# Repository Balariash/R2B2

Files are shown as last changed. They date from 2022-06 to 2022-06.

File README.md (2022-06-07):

# R2B2
Double click on index.html to open the web interface.

# Mosquitto
The file mosquitto.conf is needed to use MQTT over websockets.

Place this file in /etc/mosquitto/conf.d/ directory.

# Python
You need to specificate the IP of MQTT Broker in the variable host from config.py to use mqtt_client.py script

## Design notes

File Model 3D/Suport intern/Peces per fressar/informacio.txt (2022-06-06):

Informació sobre les peces:

Suport de la càmera:

    - El gruix de la pesa ha de ser de uns 5mm.
    - Els quatre forats petits són de 2mm de diàmetre, la mateixa mida que els forats de la càmera.
    - Els dos forats més grans són de 6mm de diàmetre per permetre passar una barra roscada.
    - El costat curt del rectangle de mesurar entre 6 i 8mm.

Suport de la batèria LIPO:
    
    - El gruix ha de ser de uns 8mm.
    - Els dos forats menors han de ser de 4mm de diàmetre.
    - Els tres forats majors han de ser de 6mm de diàmetre.

Suport de la batèria de la Raspberry:

    - El gruix ha de ser de uns 8mm.
    - Els dos forats menors han de ser de 4mm de diàmetre.
    - El forat gran ha de ser de 6mm de diàmetre.
    - Els extrems poden quedar arrodonits.

Barra de unió:

    - El gruix de la barra ha de ser de 6~7mm-
    - Els forats han de ser de 4mm.
    - Són necessàries dues peces d'aquest tipus.

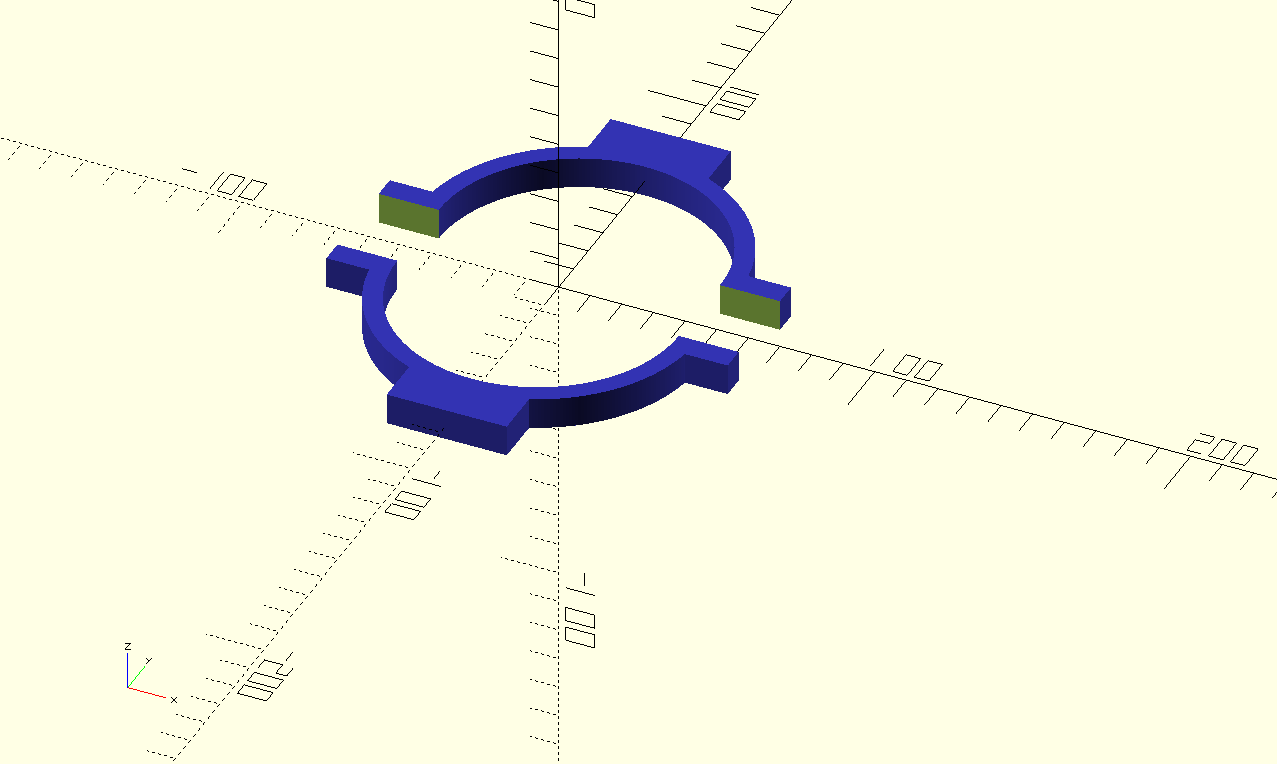
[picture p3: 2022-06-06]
Model 3D/Peces/imatges/anell_posterior_v2.png

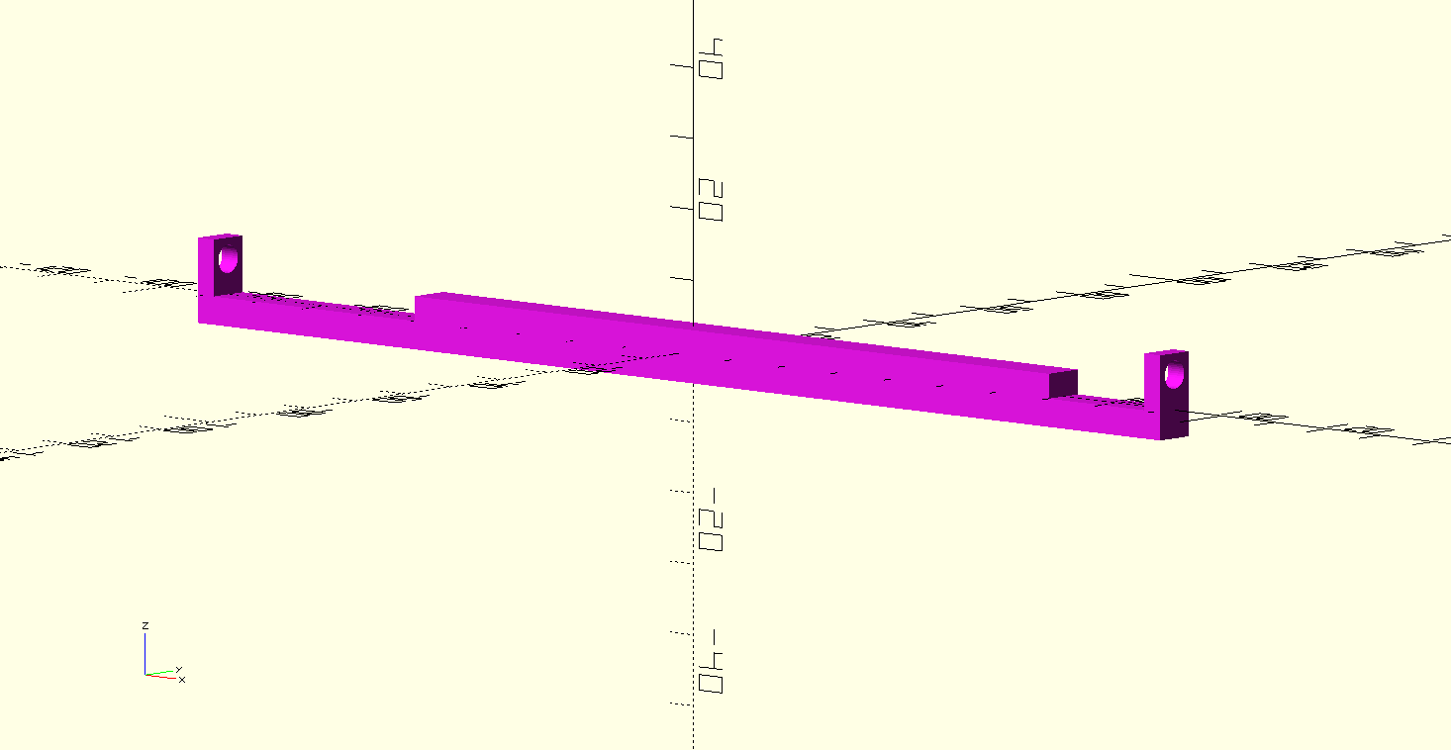
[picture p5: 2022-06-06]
Model 3D/Suport intern/Peces per fressar/Imatges/barra_unio_2.png

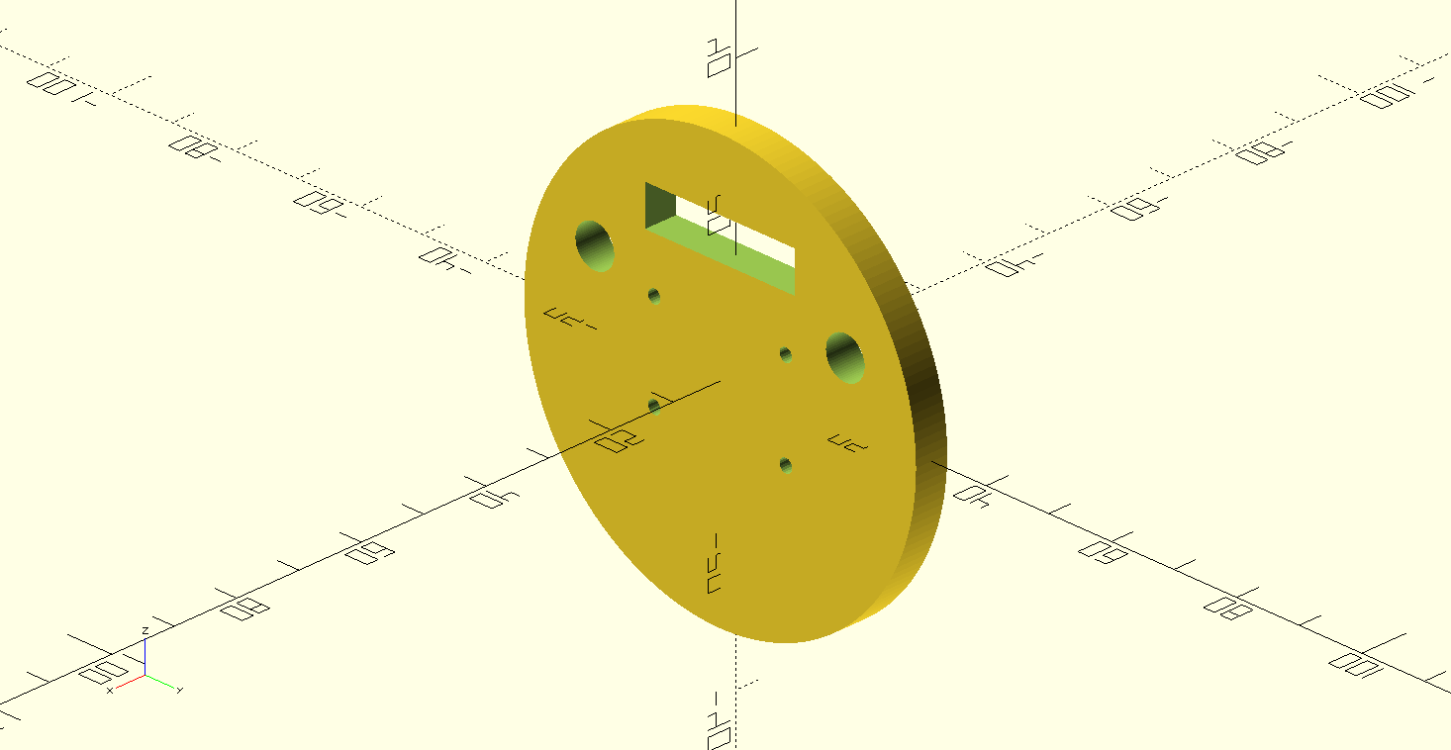
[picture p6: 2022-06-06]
Model 3D/Suport intern/Peces per fressar/Imatges/suport_camera_1.png

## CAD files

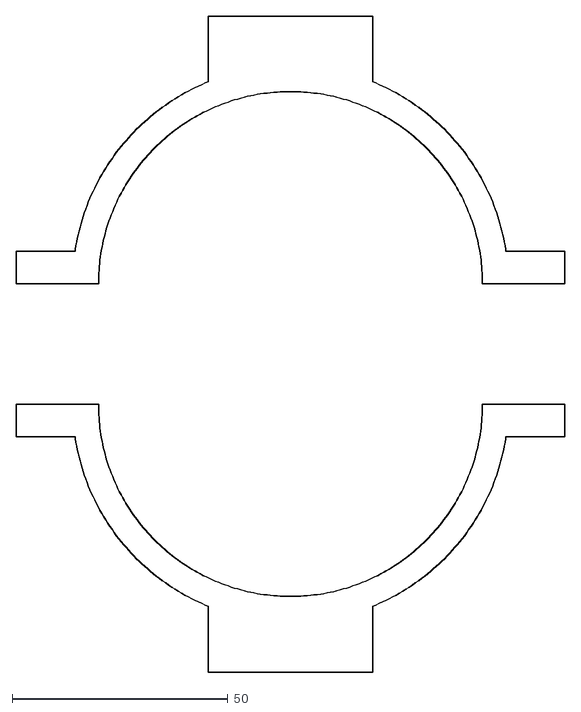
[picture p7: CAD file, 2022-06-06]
Model 3D/Peces/dxf/anell_posterior_v2.dxf
126.9 x 151.9

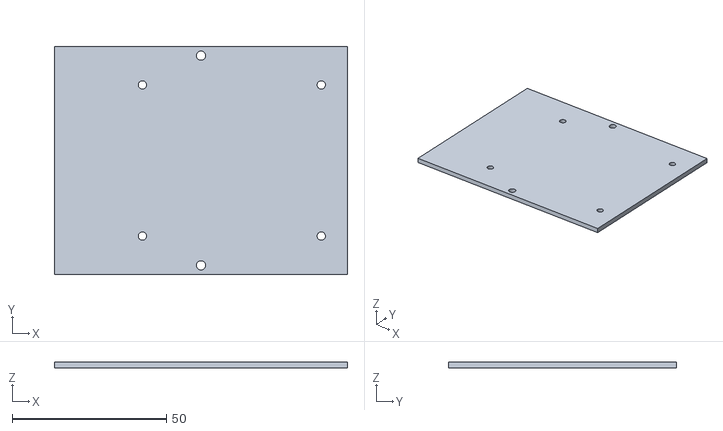
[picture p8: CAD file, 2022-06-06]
Model 3D/Suport intern/Impressió 3D/suport_raspi.stl
95.0 x 74.0 x 2.00

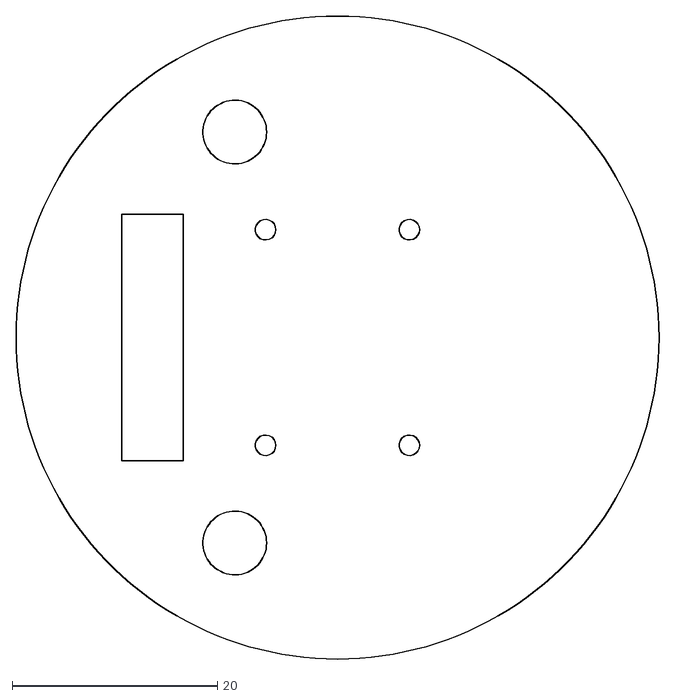
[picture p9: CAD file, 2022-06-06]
Model 3D/Suport intern/Peces per fressar/dxf/suport_camera.dxf
62.6 x 62.6

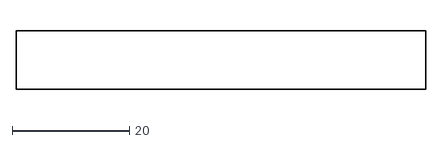
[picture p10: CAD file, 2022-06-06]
Model 3D/topes/dxf/barra.dxf
70.0 x 10.0

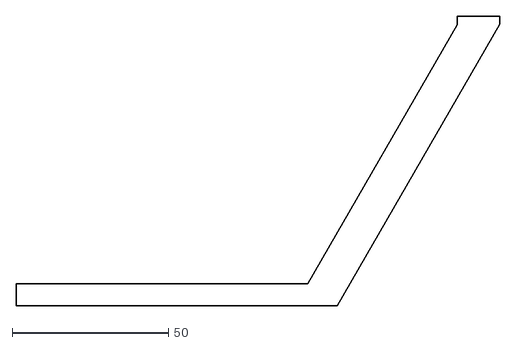
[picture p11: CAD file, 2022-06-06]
Model 3D/Peces/dxf/suport_motor_horitz.dxf
154.5 x 92.5

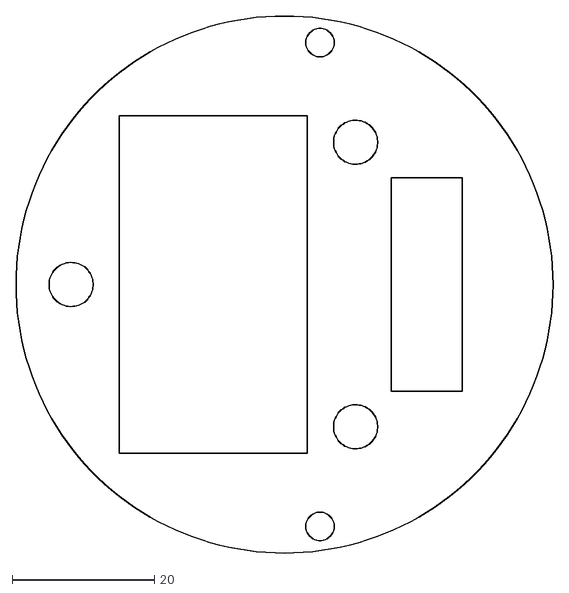
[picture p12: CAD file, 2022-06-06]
Model 3D/Suport intern/Peces per fressar/dxf/suport_lipo.dxf
75.5 x 75.5

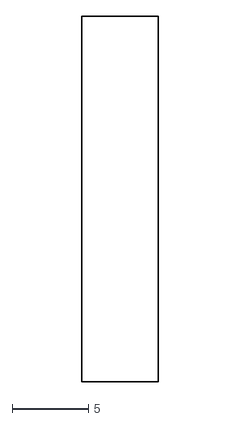
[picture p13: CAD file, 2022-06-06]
Model 3D/topes/dxf/tope_davanter.dxf
5.00 x 24.0

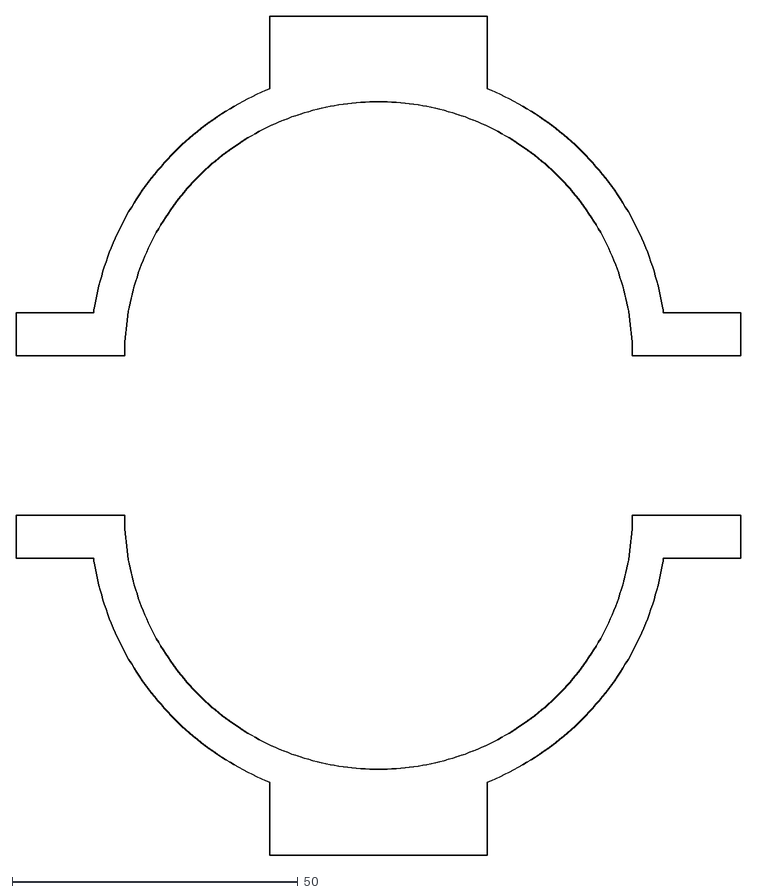
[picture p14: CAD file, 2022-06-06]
Model 3D/Peces/dxf/anell_davanter_v2.dxf
126.9 x 146.9

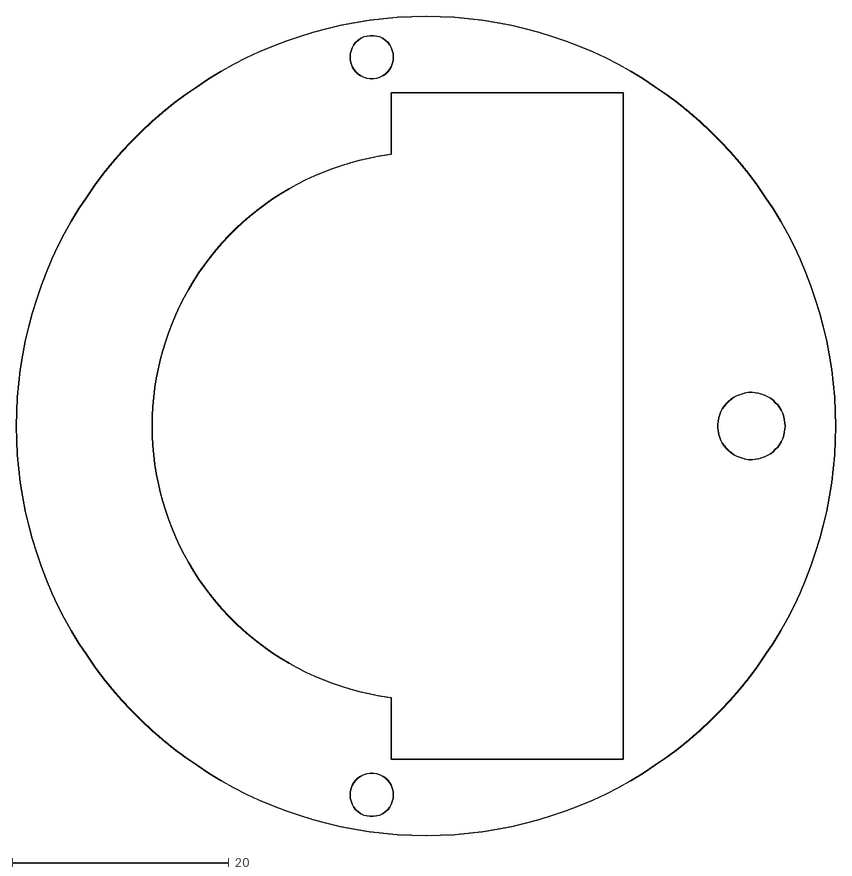
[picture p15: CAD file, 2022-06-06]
Model 3D/Suport intern/Peces per fressar/dxf/suport_bater.dxf
75.5 x 75.5

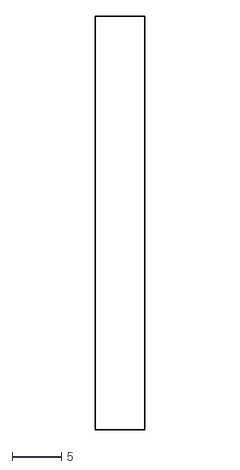
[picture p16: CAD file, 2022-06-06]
Model 3D/topes/dxf/tope_posterior.dxf
5.00 x 42.0

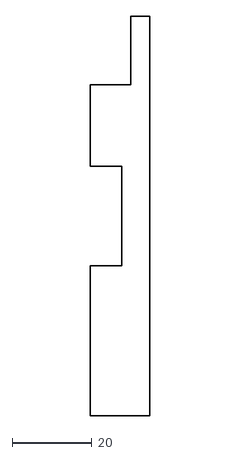
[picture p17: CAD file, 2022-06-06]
Model 3D/Peces/dxf/suport_motor_vert.dxf
15.0 x 100.0

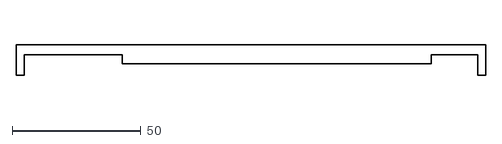
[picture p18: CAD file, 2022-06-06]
Model 3D/Suport intern/Peces per fressar/dxf/barra_unio.dxf
182.0 x 12.0

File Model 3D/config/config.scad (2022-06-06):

// Configuració general

// Cos principal
height_cyli = 298;
wall_width = 6.35;
inner_diameter = 76.2;
diameter_cyli = inner_diameter + wall_width*2;

// Motors
motor_diameter = 90;
motor_height = 39;

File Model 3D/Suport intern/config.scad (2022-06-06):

// Configuració general

// Cos principal
height_cyli = 298;
wall_width = 6.35;
inner_diameter = 76;
diameter_cyli = inner_diameter + wall_width*2;

// Bateria LIPO
w1 = 47;
h1 = 26;

// Bateria Raspi
w2 = 61;
h2 = 21;

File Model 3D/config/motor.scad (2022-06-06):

include <config.scad>
$fa = 3;
$fs = 0.3;


module perns(d=2,l=10.5){
    color([0.6,0.6,0.6]){
    translate([7.5,motor_diameter/2+6+10.5/2,16.5])
        rotate([90,0,0])
        cylinder(h=l,d=d,center=true); 
    translate([-7.5,motor_diameter/2+6+10.5/2,16.5])
        rotate([90,0,0])
        cylinder(h=l,d=d,center=true);
    translate([7.5,motor_diameter/2+6+10.5/2,-12.5])
        rotate([90,0,0])
        cylinder(h=l,d=d,center=true);
    translate([-7.5,motor_diameter/2+6+10.5/2,-12.5])
        rotate([90,0,0])
        cylinder(h=l,d=d,center=true); 
    }  
}





module motor(d=motor_diameter, h=motor_height){
    union(){
    color([0.88,0.88,0.68]){        
    difference(){
        
        union(){ 
            cylinder(h=h,d=d,center=true);
    
            translate([0,(d)/2,2])
            cube([21,12,35],center=true);
           }
        translate([0,0,0])
        cylinder(h=h+0.2,d=(d-8)+0.01,center=true);
        }
    }
    perns();
}


}
motor();

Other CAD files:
Model 3D/Peces/suport_motor_horitz.scad
Model 3D/Peces/anell_davanter_v2.scad
Model 3D/Peces/anell_posterior_v2.scad
Model 3D/Peces/suport_motor_vert.scad
Model 3D/Suport intern/barra_unio.scad
Model 3D/Suport intern/estruct_intern.scad
Model 3D/Suport intern/suport_bat.scad
Model 3D/Suport intern/suport_bater.scad
Model 3D/Suport intern/suport_camera.scad
Model 3D/Suport intern/suport_lipo.scad
Model 3D/Suport intern/suport_raspi.scad
Model 3D/config/Cos.scad
Model 3D/model_3D.scad
Model 3D/topes/barra.scad
Model 3D/topes/tope_davanter.scad
Model 3D/topes/tope_posterior.scad
Model 3D/topes/topes.scad

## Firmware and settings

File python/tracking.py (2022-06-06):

import cv2
import numpy as np
import math, random
import paho.mqtt.client as mqtt
from scipy import ndimage
from time import sleep
import json
from config import host

##################################################################

class Label():
    """
    Aquesta classe s'encarrega d'analizar la imatge binaria obtinguda
    de l'implementació de la funció cv2.connectedComponents i a partir
    d'ella determina quin es el grup de pixels més gran i de major interes
    i calcula en quin sector de la imatge es troba el seu centre
    """
    def __init__(self, labels, num_labels):
        self.labels = labels
        self.num_labels = num_labels
        self._group_size_cache = None

    def groups_size(self):
        """
        Analitza els diferents grups dins de labels per determinar
        quin es el grups de pixels més gran.
        
        Retorna el nombre del grup més gran i la quantitat de 
        pixels que inclou.

        """
        if self._group_size_cache is not None:
            return self._group_size_cache
        #
        unique, counts = np.unique(self.labels, return_counts=True)
        groups = np.asarray((unique, counts)).T
        #
        self._group_size_cache = max(groups, key=(lambda g: g[1] if g[0] else -1))
        return self._group_size_cache

    def find_center(self):
        """
        A partir del grup de pixels més gran, troba
        el centre de masses d'aquest.

        Retorna les coordenades enteres del centre.
        """
        group_num, pixels = self.groups_size()
        cy, cx = ndimage.measurements.center_of_mass(self.labels == group_num)
        return (round(cx), round(cy))

    def object_position(self):
        # Divideix la imatge en tres files i tres columnes definir en quina secció esta l'objecte
        # 00 01 02
        # 10 11 12
        # 20 21 22
        """
        Divideix la imatge en tres files i tres columnes per definir
        en quina secció esta l'objecte. (En format fila columna)
        00 01 02
        10 11 12
        20 21 22

        Retorna el número de fila, el número de columna i el percentatge de pixels
        de la imatge que conformen el grup.
        """
        x, y = self.find_center()
        height, width = self.labels.shape[0], self.labels.shape[1]
        return self.section(y, height), self.section(x, width), self.object_size()

    def section(self, y, height):
        """
        Donat la coordenada y del centre de l'objecte i l'alçada de 
        la imatge, divideix la imatge en tres files iguals i retorna 
        el número de la fila en la que es troba el centre.

        En cas de introduir la coordenada x del centre i l'amplada de
        la imatge, divideix la imatge en tres columnes iguals i retorna
        el número de la columna en la que es troba el centre.
        """
        if y < height/3:
            return 0
        elif y > 2*height/3:
            return 2
        else:
            return 1

    def object_size(self):
        """
        Determina el percentatge de pixels
        de la imatge que pertanyen al grup.

        Retorna el percentatge.
        """
        
        img_size = self.labels.size
        obj_size = self.groups_size()[1]
        return (obj_size/img_size)*100

################################################################
def on_connect(client, userdata, flags, rc):
    if rc == 0:
        client.connected_flag=True
        print("connected OK Returned code=",rc)
    else:
        print("Bad connection Returned code=",rc)
        client.bad_connection_flag=True

def connect_mqtt():
    client = mqtt.Client(client_id)
    client.username_pw_set(username, password)
    client.on_connect = on_connect
    client.connect(host, port)
    return client  
################################################################

#host = '169.254.10.124'
port = 1883

client_id = "stalker"
username = "Stalker"
password = "password"
topic = "Motors"


msg_cache = None
#################################################################
client = connect_mqtt()
client.loop_start()

'''
HSV ranges:
Hue is 0 to 179
Saturarion is 0 to 255
Value is 0 to 255

Blau:     90 - 130
Vermell:  145 - 180, 0 - 10
Verd:     40 - 89
'''
lower_color = np.array([0,100,100])
upper_color = np.array([10,255,255])

lower_color2 = np.array([170, 100, 100])
upper_color2 = np.array([189, 255, 255])

while True:
    try:
        cap = cv2.VideoCapture("http://localhost:8090/?action=stream")
        _, img = cap.read()
        #img = cv2.resize(img, None, fx=0.5, fy=0.5, interpolation=cv2.INTER_AREA)
        
    except:
        cap = cv2.VideoCapture(0)
        _, img = cap.read()
        #img = cv2.resize(img, None, fx=0.5, fy=0.5, interpolation=cv2.INTER_AREA)


    img = cv2.rotate(img, cv2.ROTATE_180)
    hsv = cv2.cvtColor(img, cv2.COLOR_BGR2HSV)
    
    mask1 = cv2.inRange(hsv, lower_color, upper_color)
    mask2 = cv2.inRange(hsv, lower_color2, upper_color2)
    mask = mask1 + mask2
    
    num_labels, labels = cv2.connectedComponents(mask, connectivity=4)   
    l = Label(labels, num_labels)
    
    py, px, size = l.object_position()
    print(size)
    if px == 1 and py == 1 and size >= 6:
        msg = "stop"
        if msg != msg_cache:
            client.publish(topic, json.dumps([msg]))
            print("stop")

    elif px == 0:
        msg = "fwd"
        if msg != msg_cache:
            client.publish(topic, json.dumps([msg, 0.2, 0.4]))
            print("fwd-l")
        
    elif px == 1:
        if py == 0:
            msg = "up"
            if msg != msg_cache:
                client.publish(topic, json.dumps([msg, 0.2, 0.2]))
                print("up")
            
        elif py == 1:
            msg = "fwd"
            if msg != msg_cache:
                client.publish(topic, json.dumps([msg, 0.3, 0.3]))
                print("fwd")
            
        elif py == 2:
            msg = "dwn"
            if msg != msg_cache:
                client.publish(topic, json.dumps([msg, 0.2, 0.2]))
                print("dwn")
            
    elif px == 2:
        msg = "fwd"
        if msg != msg_cache:
            client.publish(topic, json.dumps([msg, 0.4, 0.2]))
            print("fwd-r")
    
    else:
        #msg = "stop"
        print("No troba res")

    msg_cache = msg
    sleep(2)
 


print("Aturat")

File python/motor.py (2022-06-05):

from gpiozero import PWMOutputDevice as POD
from gpiozero.pins.pigpio import PiGPIOFactory
from time import sleep

###############################################

"""
Motor VE:
  - valor > 0.149 --> antihorari. (baixar)
  - valor < 0.149 --> horari.     (pujar)

Motor VD:
  - valor > 0.149 --> antihorari. (pujar)
  - valor < 0.149 --> horari.     (baixar)

Motor HE:
  - valor > 0.149 --> antihorari. (enrera)
  - valor < 0.149 --> horari.     (endavant)

Motor HD:
  - valor > 0.149 --> antihorari. (endavant)
  - valor < 0.149 --> horari.      (enrera)


El motiu pel qual els motors paral·les giren en sentit contrari quan
el vol moure en linea recta es degut a que tenen les hèlix invertides
i d'aquesta forma els moments dels motors s'anulen entre ells donant 
major estabilitat al robot.

"""

class Motor():
    """
    motors
    Jordi Muñoz 2021-10-30

    Aquesta clase defineix l'estat d'un motor.

    Parameters:
      pin :      int
      Número de pin GPIO de la raspberry ha utilitzar.
      
    """

    DEFAULT_SPEED = 0
    
    def __init__(self, pin):
        # Important especificar la llibreria de pins PiGPIO al usar PWM.
        self.motor = POD(pin=pin, pin_factory=PiGPIOFactory())

        # Procés d'inicialització dels motors.
        self.motor.off()
        sleep(0.5)
        self.motor.on()
        sleep(0.5)

        # Per començar a funcionar, es necessari que el valor inicial del pin sigui 0.149
        self.motor.value = 0.149
        self.speed = self.DEFAULT_SPEED

    def motor_speed(self, spd=None):
        """
        Determina la velocitat a la que es mou el motor.

        spd : float, entre 0 i 1
        
        Retorna el valor de velocitat a la que gira el motor.
        """
        if spd is not None:
            self.speed = spd * 0.006
            return self.speed

        return self.speed

    def horari(self, spd=None):
        """
        Fa girar el motor en sentit horari.
        """
        self.motor.value = 0.147 - self.motor_speed(spd)
        print(self.motor.value)
        
    def antihorari(self, spd=None):
        """
        Fa girar el motor en sentit antihorari.
        """
        self.motor.value = 0.152 + self.motor_speed(spd)
        print(self.motor.value)

    def stop(self):
        """
        Atura el motor
        """
        self.motor.value = 0.149
        
    def off(self):
        """
        Apaga el pin
        """
        self.motor.off()
        print('off')

    def on(self):
        """
        Encen el pin
        """
        self.motor.off()
        print("on")

    def show_value(self):
        """
        Mostra el valor del pin.
        """
        print(self.motor.value)
